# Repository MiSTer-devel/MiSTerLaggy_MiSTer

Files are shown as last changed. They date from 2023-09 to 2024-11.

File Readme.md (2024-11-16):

# MiSTer Laggy

MiSTer Laggy is a display latency tester for use with the MiSTer FPGA system. It consists of a core that runs on the MiSTer DE-10 and a light sensor that connects to the MiSTer's User Port. It operates on the same principle as the [Time Sleuth](https://github.com/chriz2600/time-sleuth) but takes advantage of an existing platform to generate the video signal and capture the measurements.

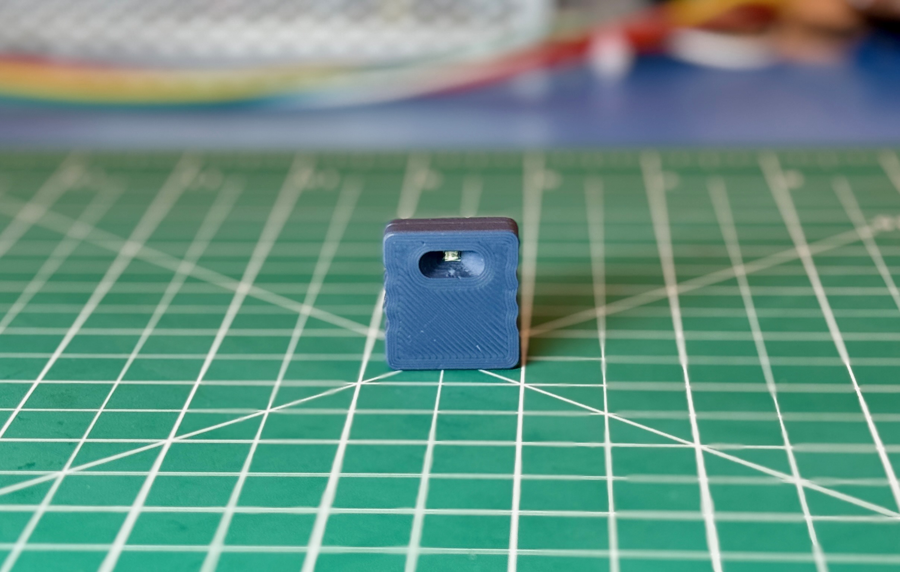
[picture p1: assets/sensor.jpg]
Sensor


## Setup
* Copy the latest core from the `releases/` directory to your MiSTer
* Connect the MiSTer Laggy sensor to the User Port with a USB A-C cable
* Launch the MiSTer Laggy core

## Basic Operation
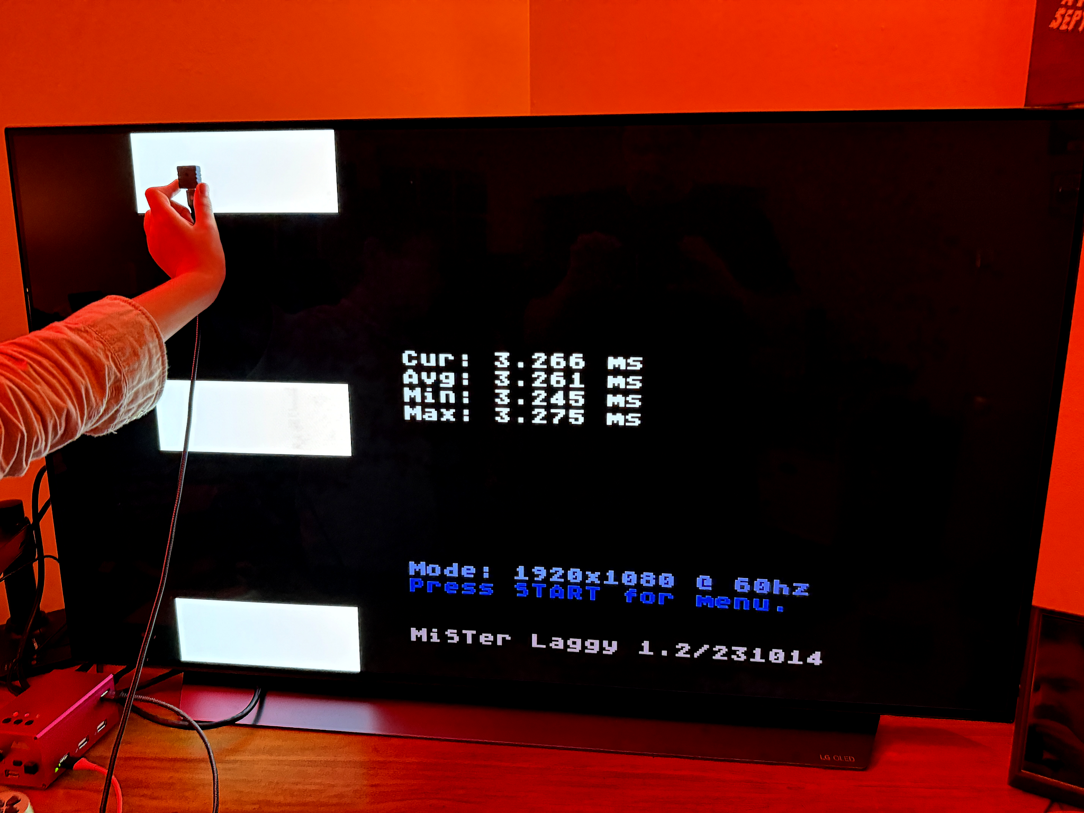
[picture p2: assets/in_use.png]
In Use

The system works by flashing a test pattern on the screen and measuring how long it takes for that pattern to be seen by the sensor. The measured latency is show in the center of the screen, along with the average, min and max measures. There are three areas in the test pattern why you can place the sensor, so you can measure latency at the top, middle and bottom of the screen.

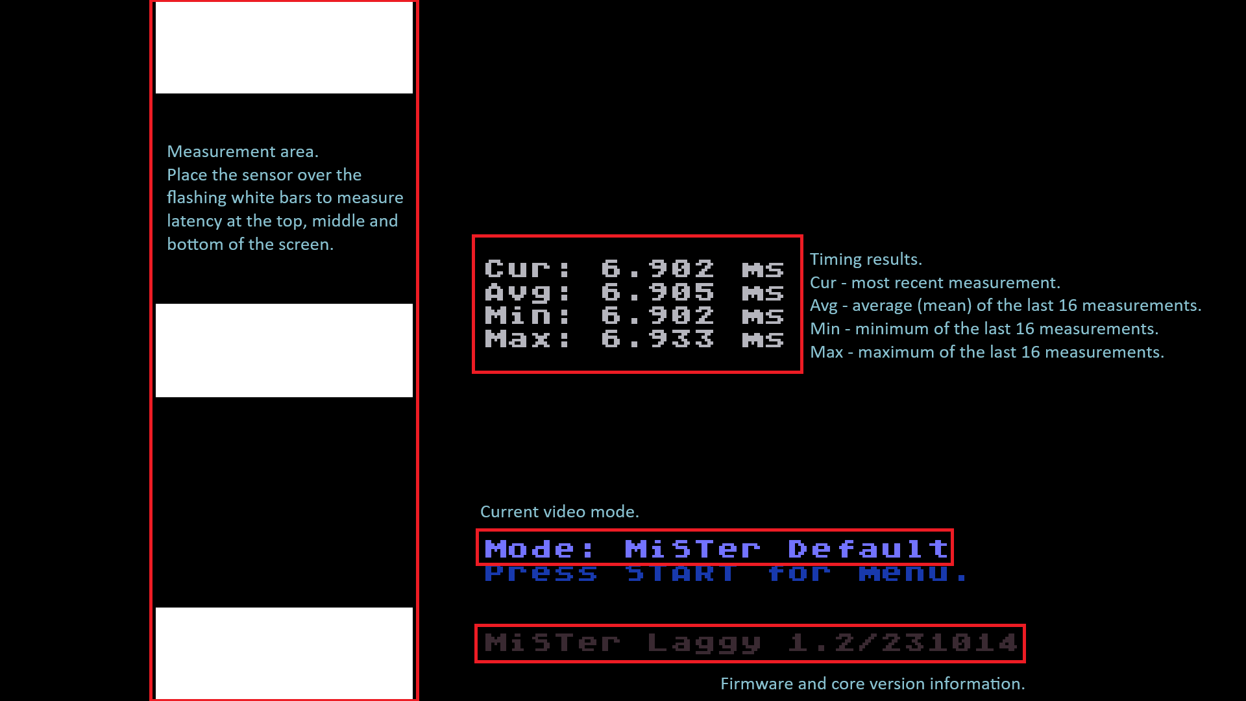
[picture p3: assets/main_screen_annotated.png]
Annotated Main Screen


## Video Modes
On startup or after a reset, the core uses whatever video mode and `vsync_adjust` settings you have configured in your MiSTer INI file. When running in this mode it will display `Mode: MiSTer Default` on the main screen. You can change the current video mode in the _Video Config_ menu which you access by pressing the START button on your controller.

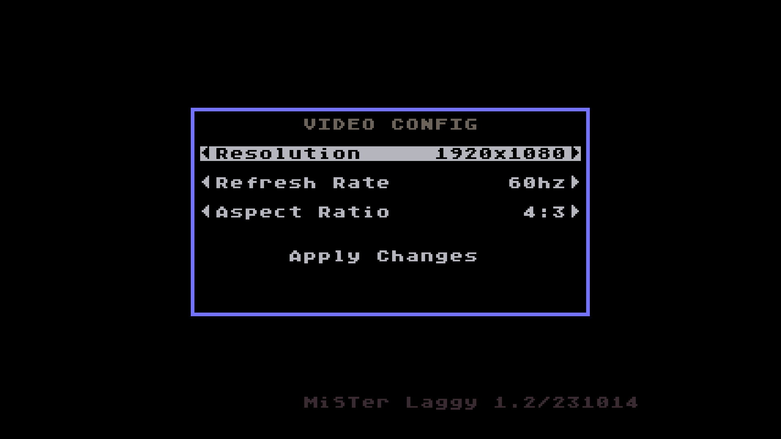
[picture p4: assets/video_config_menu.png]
Video Config Menu


In the Video Config menu you can select between several resolutions and refresh rates. Up/Down on your controller selects between the options while Left/Right adjusts each value. You can press B or Start to back out of the menu at any time. To apply the changes and switch to the mode you have selected, highlight the _Apply Changes_ option and press A. The core will switch to the new video mode and return to the main screen. The new mode will now be displayed in the `Mode:` area.

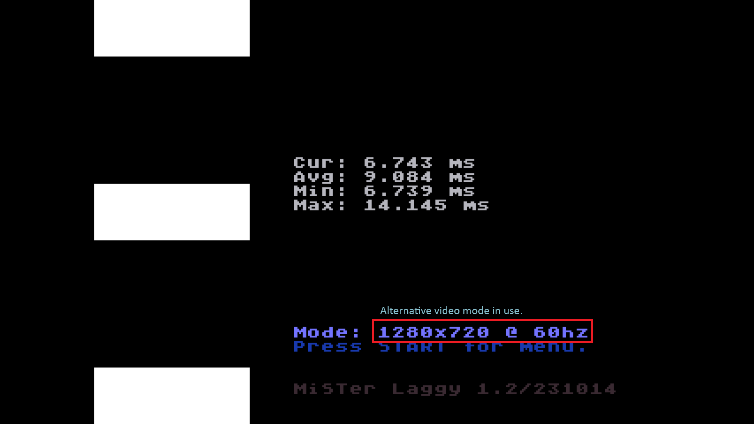
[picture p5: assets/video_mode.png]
Alternative Mode


It's possible that your display does not support the display mode that you have selected. If that happens you can just reset the core by pressing the `User` button on your IO board or just power cycle your MiSTer. None of the changes set in the Video Config menu are permanent.

## Timing Details
MiSTer Laggy starts counting latency from the moment the vertical blank ends. Assuming there is no overscan or other scaling enabled on your display, this will be the where the first visible line in drawn on your screen. With HDMI output on MiSTer there are two different vertical blanks, the vertical blank created by the core itself and the vertical blank created by the scaler. The scaler vertical blank occurs after the cores vertical blank, how long after depends on the `vsync_adjust` setting you are using in your INI.

When the MiSTer Laggy core starts up and is in the `MiSTer Default` video mode, it uses the end of the vertical blank from the core as the start of the measurement. This means that any latency introduced by MiSTer's ASCAL scaler will also be measured. You could, for instance, experiment with different `vsync_adjust` settings and see how they impact the total latency.

When you switch modes in the Video Config menu, the core will start using the end of the HDMI vertical blank, which is generated by the scaler, as the start of the measurement period. This means only the display latency will be measured, and any additional time spent in the MiSTers scaler will not be included. 

## Hardware
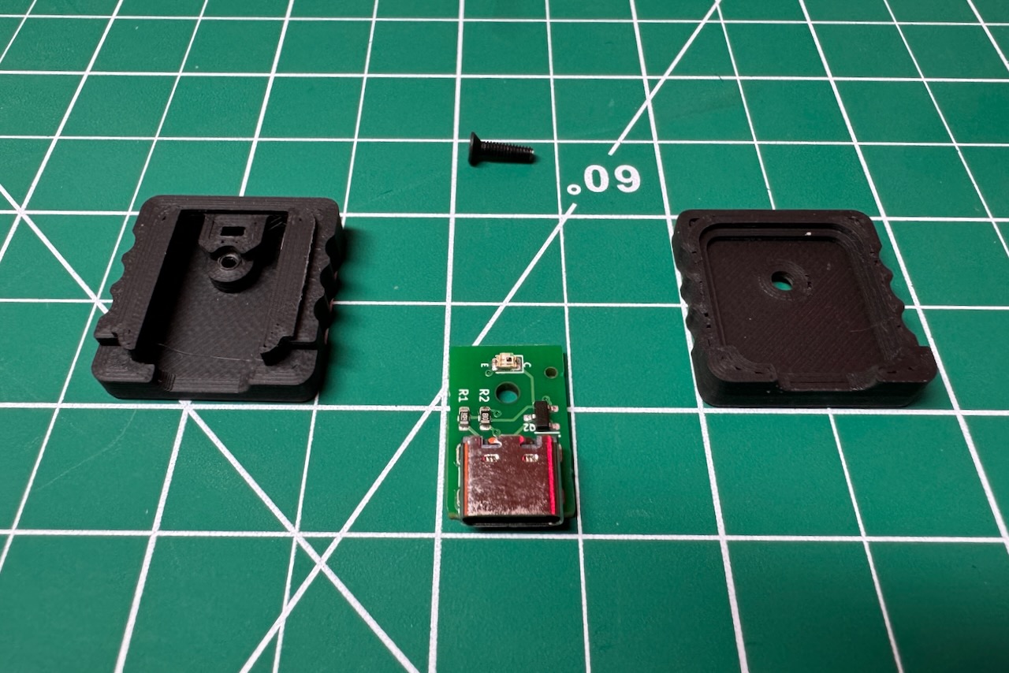
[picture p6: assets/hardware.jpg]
Hardware

The MiSTer Laggy hardware is very simple. It consists of a small PCB with a photo transistor alongside a few components to allow it to interface with the user port, and a 3D printed case. The case is designed to prevent any external light from reaching the sensor. It snaps together tightly and is secured with a M2x8 flat head screw. The PCB is all surface mounted components and uses a compact USB-C connector.

The `hardware/` directory contains KiCAD project files for the PCB along with STEP and STL files for the case.

## Additional Assets
32x32 MiSTer Kun logo - https://github.com/baxysquare/mister_kun

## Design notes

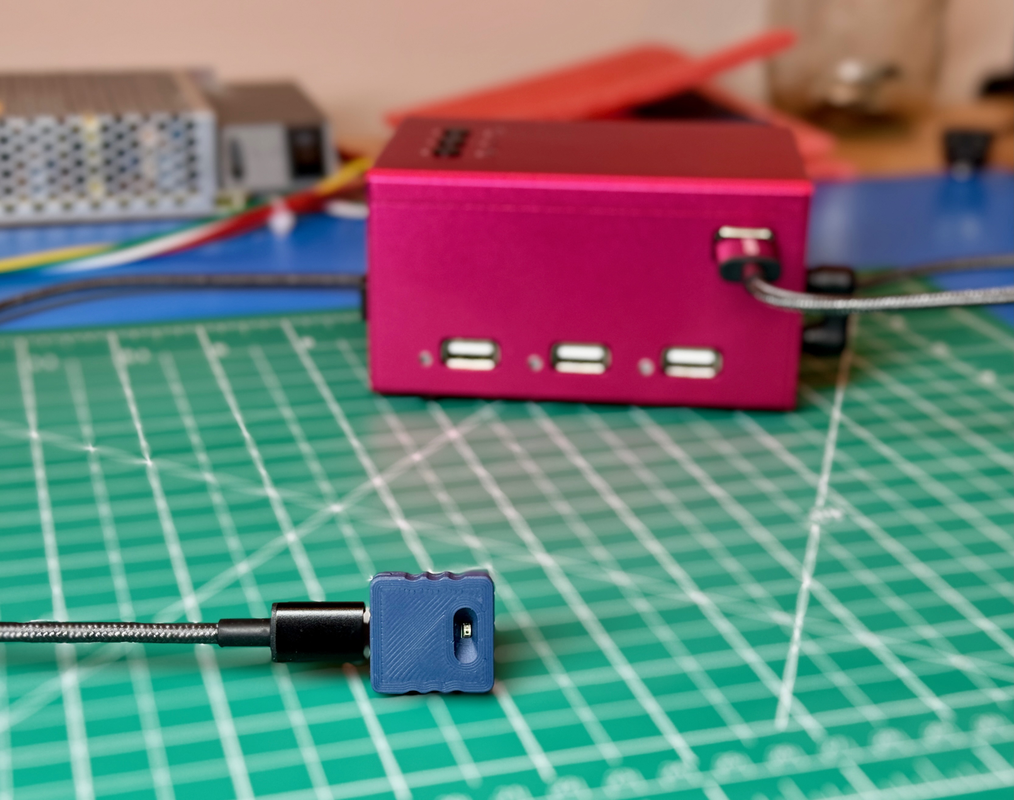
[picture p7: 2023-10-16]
assets/sensor_with_mister.jpg

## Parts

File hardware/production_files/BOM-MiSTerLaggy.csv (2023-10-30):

Comment | Designator | Footprint | LCSC
PT17-21C/L41/TR8 | Q1 | LED_0805_2012Metric | C100090
1K | R2 | R_0603_1608Metric | C21190
300K | R1 | R_0603_1608Metric | C23024
USB_C_Receptacle_USB2.0 | J1 | USB_C_Receptacle_G-Switch_GT-USB-7010ASV | C2988369
2N7002 | Q2 | SOT-23 | C8545

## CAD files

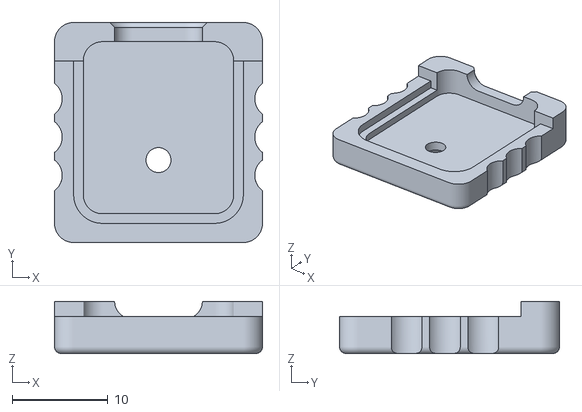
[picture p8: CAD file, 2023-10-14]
hardware/Case - Back Side.stl
21.7 x 23.0 x 5.43

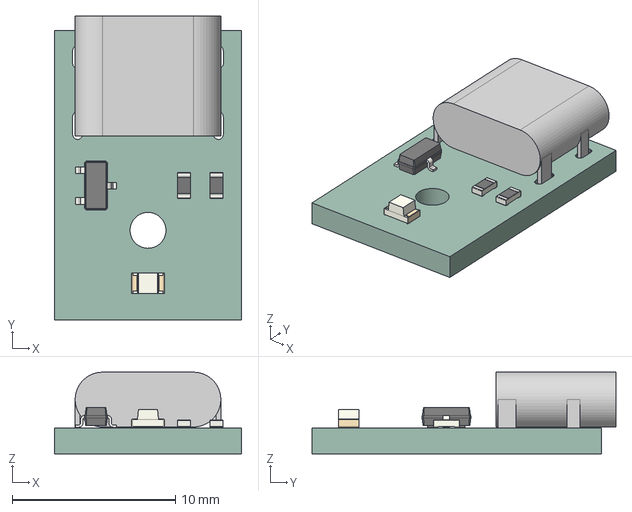
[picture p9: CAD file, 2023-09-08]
hardware/SMD/MiSTerLaggy.step
11.5 x 18.6 x 5.01 mm
MiSTerLaggy PCB

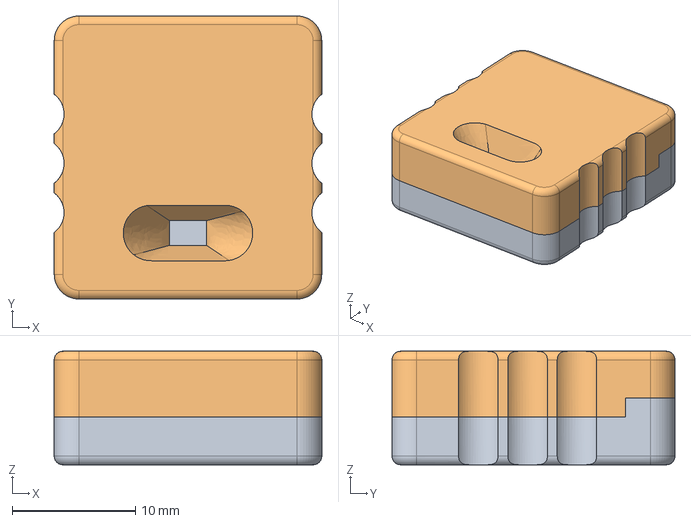
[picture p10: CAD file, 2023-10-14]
hardware/Case.step
21.7 x 22.9 x 9.21 mm

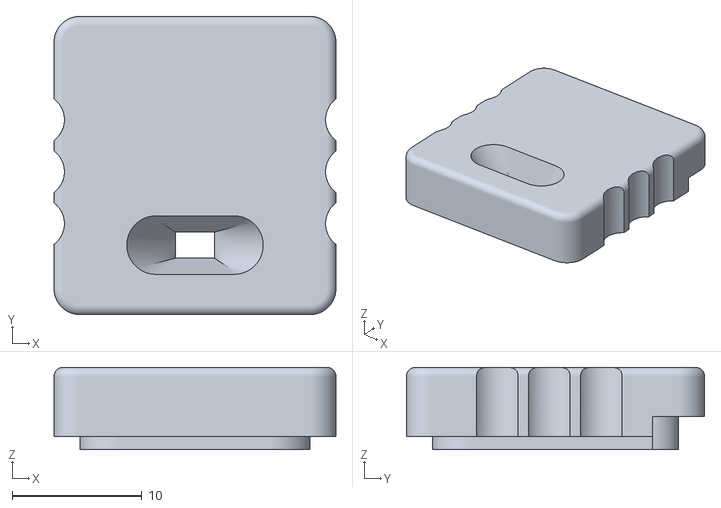
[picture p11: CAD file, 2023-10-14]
hardware/Case - Sensor Side.stl
21.7 x 23.0 x 6.33

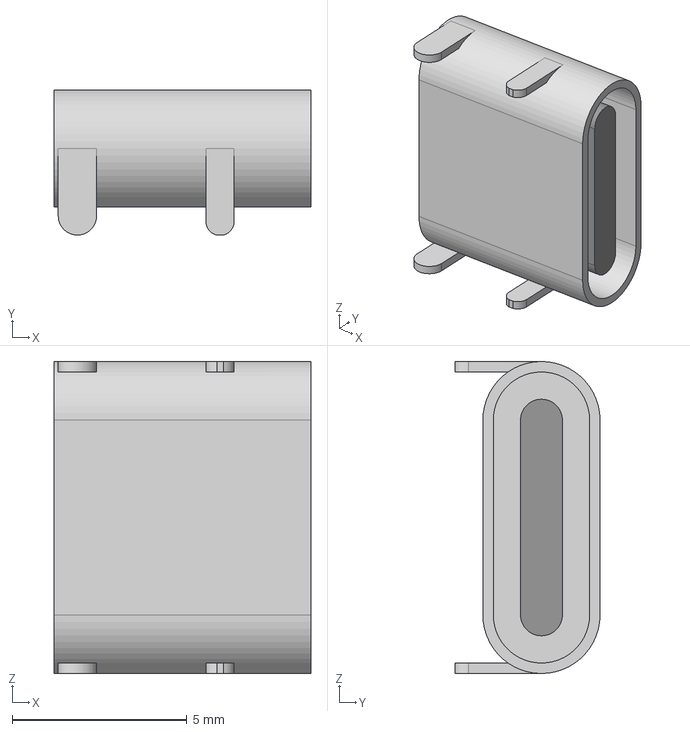
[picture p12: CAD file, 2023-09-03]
hardware/GT-USB-7010ASV.step
7.35 x 4.16 x 8.94 mm

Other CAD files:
hardware/MiSTerLaggy-PCB.step

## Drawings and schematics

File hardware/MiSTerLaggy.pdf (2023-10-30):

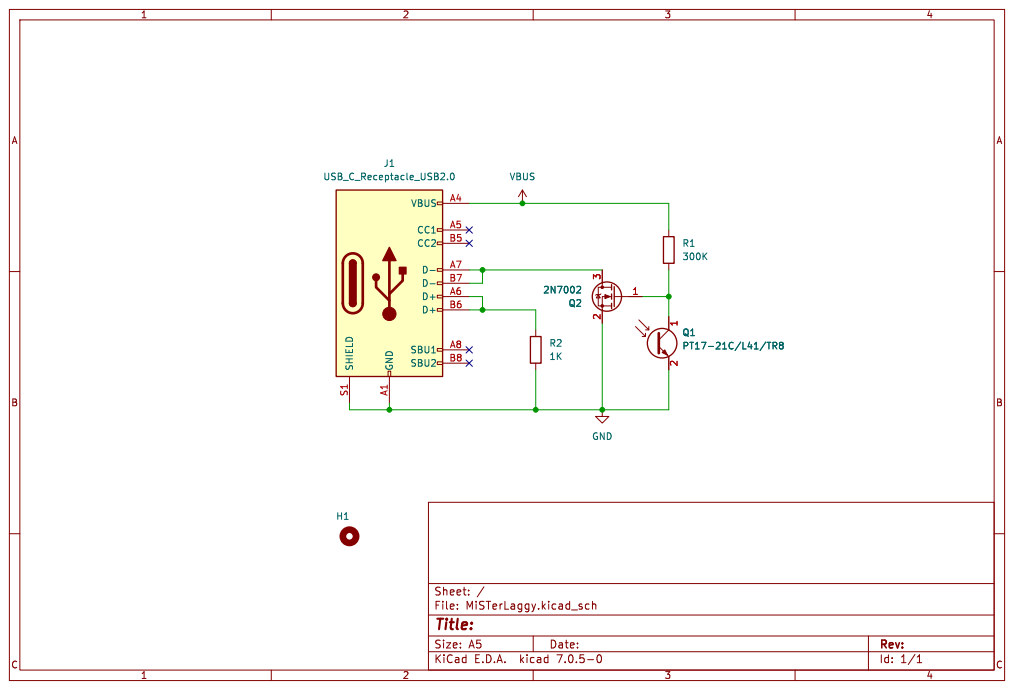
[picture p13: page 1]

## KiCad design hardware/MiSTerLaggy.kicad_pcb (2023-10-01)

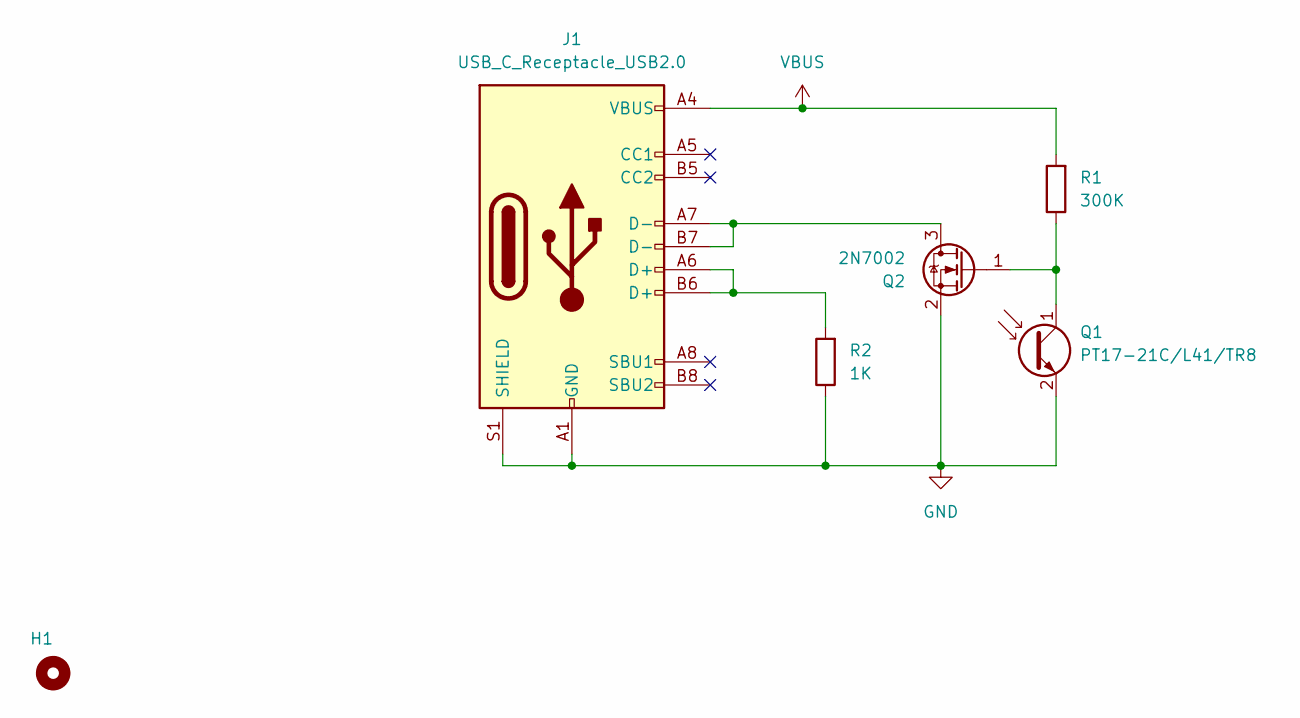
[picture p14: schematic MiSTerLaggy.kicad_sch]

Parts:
H1: MountingHole; MountingHole_2.2mm_M2_ISO7380
J1: USB_C_Receptacle_USB2.0; USB_C_Receptacle_G-Switch_GT-USB-7010ASV
Q1: PT17-21C/L41/TR8; LED_0805_2012Metric
Q2: 2N7002; SOT-23
R1: 300K; R_0603_1608Metric
R2: 1K; R_0603_1608Metric

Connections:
GND: J1.A1 (GND), J1.A12 (GND), J1.B1 (GND), J1.B12 (GND), J1.S1 (SHIELD), Q1.2 (E), Q2.2 (S), R2.1
unnamed: J1.A6 (D+), J1.B6 (D+), R2.2
unnamed: Q1.1 (C), Q2.1 (G), R1.1
unnamed: J1.A7 (D-), J1.B7 (D-), Q2.3 (D)
VBUS: J1.A4 (VBUS), J1.A9 (VBUS), J1.B4 (VBUS), J1.B9 (VBUS), R1.2

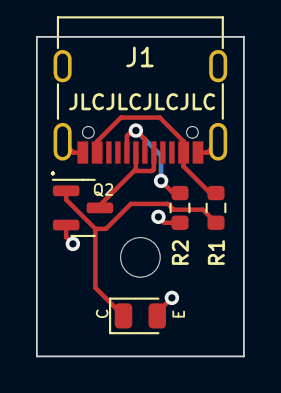
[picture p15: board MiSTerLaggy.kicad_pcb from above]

Board: 2 copper layers, 11.5 x 17.8 mm, 6 parts (0 on the bottom side), 5 nets.

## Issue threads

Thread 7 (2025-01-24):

Won't get past "No sensor detected!"

AndreTheShepherd, 2025-01-24:
Hi,

using MiSTer Laggy 1.3/241113
Sensor connected to User Port at the IO Board
I tried different cables, but I cannot get past the "No sensor detected" message.

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

Mister ini attached. [MiSTer_test_ini.txt](https://github.com/user-attachments/files/18539704/MiSTer_test_ini.txt)

I'd love to rule out a hardware issue with the sensor itself. Do you have a hint how to test the sensor hardware for functionality?

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

Any other ideas what I can try?

Thanks a lot for the great work and support.

Kindest regards

wickerwaka, 2025-01-24:
The detection is really basic. That R2 resistor pulls down one of the signals and that is what the software looks for. If there is no obvious physical damage to the port or the PCB then I would suspect something else.

Have you tried with a different cable?
Have you ever had anything else connected and working in the User IO port?
Does you IO board have the required pins for the user IO port to work? Sometimes they are no installed by manufacturers.

AndreTheShepherd, 2025-01-26:
The hardware of the sensor looks fine, port and all the surface mounted components

Tried different cables: CHECK, 3 different cable. That should be fine
Anything else on the User Port: NOPE ...

wickerwaka, 2025-02-01:
Perfect! Thank you for posting the solution.

Closed 2025-02-01.

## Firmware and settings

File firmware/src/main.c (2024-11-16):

#include <stdint.h>
#include <stdbool.h>
#include "printf/printf.h"

#include "util.h"
#include "interrupts.h"
#include "input.h"
#include "hdmi.h"
#include "gfx.h"
#include "clock.h"
#include "debug.h"

#define FIRMWARE_VERSION "1.3"

#define RGB(r, g, b) ( ( ((r) & 0xf8) << 7 ) | ( ((g) & 0xf8) << 2 ) | ( ((b) & 0xf8) >> 3 ) )

#define WAIT_CLEAR_TICKS CLOCK_MS_TO_TICKS(200)
#define MIN_SAMPLE_TICKS CLOCK_MS_TO_TICKS(200)
#define MAX_SAMPLE_TICKS CLOCK_MS_TO_TICKS(500)

uint16_t *palette_ram = (uint16_t *)0x920000;
volatile uint16_t *user_io = (volatile uint16_t *)0x300000;
uint16_t *int_ctrl = (uint16_t *)0x700000;
uint32_t *core_version = (uint32_t *)0xf00000;

#define INT2_CTRL(x) (((x) & 0xf) << 0)
#define INT4_CTRL(x) (((x) & 0xf) << 4)
#define INT6_CTRL(x) (((x) & 0xf) << 8)
#define INT_SRC_NONE 0
#define INT_SRC_VBLANK 1
#define INT_SRC_HDMI_VBLANK 2
#define INT_SRC_USERIO 3
#define INT_INVERT 0x8


volatile uint32_t vblank_int_count = 0;

volatile uint16_t sample_seq = 0; 
volatile uint16_t frame_seq = 0;
volatile uint16_t sensor_seq = 0;

volatile uint32_t frame_ticks = 0;
volatile uint32_t sensor_ticks = 0;


__attribute__((interrupt)) void level2_handler()
{
    DEBUG_FRAME_MARKER(vblank_start);
    vblank_int_count++;
}

__attribute__((interrupt)) void level4_handler()
{
    if (frame_seq != sample_seq)
    {
        frame_ticks = clock_get_ticks();
        frame_seq = sample_seq;
    }

    DEBUG_FRAME_MARKER(vblank_end);
}

__attribute__((interrupt)) void level6_handler()
{
    if (sensor_seq != sample_seq)
    {
        sensor_ticks = clock_get_ticks();
        sensor_seq = sample_seq;
    }
}


static uint32_t rand_state = 0xdeadbeef;
uint32_t rand32()
{
 	uint32_t x = rand_state;
	x ^= x << 13;
	x ^= x >> 17;
	x ^= x << 5;
    rand_state = x;
	return x;
}


#define STATUS_W 16
#define STATUS_H 4
typedef struct
{
    char lines[STATUS_H][STATUS_W+1];
    uint8_t colors[STATUS_H];
} StatusInfo;

StatusInfo status;

int test_position = 0;
static inline Align align_test()
{
    return test_position == 0 ? ALIGN_LEFT : ALIGN_RIGHT;
}

static inline Align align_info()
{
    return test_position == 0 ? ALIGN_RIGHT : ALIGN_LEFT;
}

char video_mode_desc[32];

static void draw_status()
{
    gfx_begin_window(ALIGN_MIDDLE | align_info(), 2, -2, 24, STATUS_H, 0);

    for( int i = 0; i < STATUS_H; i++ )
    {
        gfx_pen(status.colors[i]);
        gfx_text(status.lines[i]);
    }

    gfx_end_window();
}

typedef struct
{
    uint16_t width;
    uint16_t height;
    bool wide;
} HDMIResolution;

static const HDMIResolution hdmi_resolutions[] =
{
    {  640,  480, false },
    {  800,  600, false },
    { 1280,  720, true },
    { 1024,  768, false },
    { 1366,  768, false },
    { 1280,  960, false },
    { 1708,  960, true },
    { 1920, 1080, true },
    { 1600, 1200, false },
    { 1792, 1344, false },
    { 1920, 1440, false },
    { 2048, 1536, false }
};

static const int hdmi_refresh_rates[] =
{
    24,
    30,
    50,
    51,
    52,
    53,
    54,
    55,
    56,
    57,
    58,
    59,
    60,
    61,
    62,
    63,
    64,
    65,
    72
};

static const char *resolution_to_string(const void *options, int index)
{
    static char tmp[32];

    const HDMIResolution *res = (const HDMIResolution *)options;

    snprintf(tmp, sizeof(tmp), "%ux%u", res[index].width, res[index].height);

    return tmp;
}

static const char *refresh_to_string(const void *options, int index)
{
    static char tmp[10];

    const int *hz = (const int *)options;

    snprintf(tmp, sizeof(tmp), "%dhz", hz[index]);

    return tmp;
}

static bool draw_menu(bool reset)
{
    static int mode_idx = 0;
    static int refresh_idx = 0;
    static int aspect_idx = 0;
    static int applied_mode_idx = -1;
    static int applied_refresh_idx = -1;
    static int applied_aspect_idx = -1;

    static MenuContext menuctx = INIT_MENU_CONTEXT;

    bool close_menu = false;

    if (reset)
    {
        if (applied_mode_idx >= 0)
        {
            mode_idx = applied_mode_idx;
            refresh_idx = applied_refresh_idx;
            aspect_idx = applied_aspect_idx;
        }
        else
        {
            mode_idx = 7;
            refresh_idx = 12;
            aspect_idx = 0;
        }
    }

    gfx_clear();

    gfx_begin_menu("CONFIG", 28, 18, &menuctx);
    
    gfx_menuitem_select_func("Resolution", hdmi_resolutions, ARRAY_COUNT(hdmi_resolutions), resolution_to_string, &mode_idx);
    gfx_menuitem_select_func("Refresh Rate", hdmi_refresh_rates, ARRAY_COUNT(hdmi_refresh_rates), refresh_to_string, &refresh_idx);

    if (hdmi_resolutions[mode_idx].wide)
    {
        const char *aspects[2] = { "4:3", "16:9" };
        gfx_menuitem_select("Aspect Ratio", aspects, 2, &aspect_idx);
    }
    else
    {
        gfx_newline(2);
    }

    gfx_newline(1);

    if (mode_idx != applied_mode_idx || refresh_idx != applied_refresh_idx || aspect_idx != applied_aspect_idx)
    {
        if (gfx_menuitem_button("Apply Video Changes"))
        {
            bool wide = hdmi_resolutions[mode_idx].wide && (aspect_idx == 1);
            *int_ctrl = INT2_CTRL(INT_SRC_VBLANK) | INT4_CTRL(INT_SRC_HDMI_VBLANK | INT_INVERT) | INT6_CTRL(INT_SRC_USERIO);
            gfx_set_240p(hdmi_refresh_rates[refresh_idx], wide);
            hdmi_set_mode(hdmi_resolutions[mode_idx].width, hdmi_resolutions[mode_idx].height, hdmi_refresh_rates[refresh_idx]);
            applied_mode_idx = mode_idx;
            applied_refresh_idx = refresh_idx;
            applied_aspect_idx = aspect_idx;
            close_menu = true;

            snprintf(video_mode_desc, sizeof(video_mode_desc), "%s @ %s",
                        resolution_to_string(hdmi_resolutions, mode_idx),
                        refresh_to_string(hdmi_refresh_rates, refresh_idx));
        }
    }

    gfx_newline(2);
    const char *test_positions[2] = { "Left", "Right" };
    gfx_menuitem_select("Test Position", test_positions, 2, &test_position);

    gfx_end_menu();

    if (input_pressed() & (INPUT_MENU | INPUT_BACK))
    {
        close_menu = true;
    }

    return !close_menu;
}

uint32_t vblank_count = 0;
void wait_vblank()
{
    while (vblank_count == vblank_int_count) {};

    vblank_count = vblank_int_count;
}

typedef enum
{
    ST_CLEAR = 0,
    ST_WAIT_CLEAR,
    ST_START_SAMPLE,
    ST_WAIT_SAMPLE,
    ST_END_SAMPLE,
} State;

State state = ST_CLEAR;
uint32_t state_start_ticks;

static void set_state(State s)
{
    state = s;
    state_start_ticks = clock_get_ticks();
}

int ticks_to_ms_str(uint32_t ticks, char *str, int len)
{
    uint32_t ms, us;
    clock_ticks_to_ms_us(ticks, &ms, &us);
    return snprintf(str, len, "%u.%03u", ms, us);
}

#define HISTORY_SIZE 16
uint32_t samples[HISTORY_SIZE];
uint32_t latest_sample;
uint32_t sample_idx = 0;
typedef enum
{
    NO_SAMPLE,
    NEW_SAMPLE,
    MISSING_SAMPLE
} SampleStatus;

SampleStatus sample_status;

void record_new_sample(uint32_t ticks)
{
    latest_sample = ticks;
    samples[sample_idx % HISTORY_SIZE] = ticks;
    sample_idx++;
    sample_status = NEW_SAMPLE;
}

void record_missing_sample()
{
    sample_status = MISSING_SAMPLE;
}

void update_sample_status()
{
    uint32_t min_ticks = 0xffffffff;
    uint32_t max_ticks = 0x00000000;
    uint32_t total_ticks = 0;

    int history_len = HISTORY_SIZE > sample_idx ? sample_idx : HISTORY_SIZE;

    for( int i = 0; i < history_len; i++ )
    {
        uint32_t ticks = samples[i];
        total_ticks += ticks;

        if (ticks > max_ticks) max_ticks = ticks;
        if (ticks < min_ticks) min_ticks = ticks;
    }

    uint32_t mean_ticks = total_ticks / history_len;

    status.colors[0] = TEXT_GRAY;
    status.colors[1] = TEXT_GRAY;
    status.colors[2] = TEXT_GRAY;
    status.colors[3] = TEXT_GRAY;

    char ms_str1[16], ms_str2[16];
    ticks_to_ms_str(latest_sample, ms_str1, 16);
    ticks_to_ms_str(mean_ticks, ms_str2, 16);
    snprintf(status.lines[0], STATUS_W, "Cur: %s ms", ms_str1);
    snprintf(status.lines[1], STATUS_W, "Avg: %s ms", ms_str2);

    ticks_to_ms_str(min_ticks, ms_str1, 16);
    ticks_to_ms_str(max_ticks, ms_str2, 16);
    snprintf(status.lines[2], STATUS_W, "Min: %s ms", ms_str1);
    snprintf(status.lines[3], STATUS_W, "Max: %s ms", ms_str2);
}

typedef enum { MODE_NO_SENSOR, MODE_SAMPLING, MODE_MENU } MainMode;

#define BAR_W 11
#define BAR_H 4

void do_sampling()
{
    uint32_t cur_ticks = clock_get_ticks();
    uint32_t state_ticks = cur_ticks - state_start_ticks;

    switch (state)
    {
        case ST_CLEAR:
            palette_ram[0x80] = 0x0000;
            set_state(ST_WAIT_CLEAR);
            break;

        case ST_WAIT_CLEAR:
            if (state_ticks >= WAIT_CLEAR_TICKS)
            {
                set_state(ST_START_SAMPLE);
            }
            break;

        case ST_START_SAMPLE:
            set_state(ST_WAIT_SAMPLE);
            palette_ram[0x80] = 0xffff;
            sample_seq++;
            DEBUG_FRAME_MARKER(sample_start);
            break;

        case ST_WAIT_SAMPLE:
            if (state_ticks < MIN_SAMPLE_TICKS)
            {
                break;
            }

            if (state_ticks > MAX_SAMPLE_TICKS)
            {
                set_state(ST_CLEAR);
                record_missing_sample();
            }
            else if (sample_seq == frame_seq && sample_seq == sensor_seq)
            {
                set_state(ST_CLEAR);
                if (frame_ticks >= sensor_ticks)
                {
                    record_missing_sample();
                }
                else
                {
                    uint32_t tick_diff = sensor_ticks - frame_ticks;
                    record_new_sample(tick_diff);
                }
            }
            break;

        default:
            set_state(ST_CLEAR);
            break;
    }


    gfx_clear();
    gfx_pen(TEXT_DARK_GRAY);
    gfx_display_border();

    gfx_pen(0x80);

    int16_t rx, ry;
    gfx_align_box(align_test() | ALIGN_TOP, 0, 0, BAR_W, BAR_H, &rx, &ry);
    gfx_rect(rx, ry, BAR_W, BAR_H);

    gfx_align_box(align_test() | ALIGN_MIDDLE, 0, 0, BAR_W, BAR_H, &rx, &ry);
    gfx_rect(rx, ry, BAR_W, BAR_H);

    gfx_align_box(align_test() | ALIGN_BOTTOM, 0, 0, BAR_W, BAR_H, &rx, &ry);
    gfx_rect(rx, ry, BAR_W, BAR_H);

    gfx_align_box(align_info() | ALIGN_TOP, 2, 2, 4, 4, &rx, &ry);
    if ((rand32() & 0xff33) == 0x0000)
        gfx_image(0x80 + 16, 0x40, rx, ry, 4, 4);
    else
        gfx_image(0x80, 0x40, rx, ry, 4, 4);

    gfx_begin_window(ALIGN_BOTTOM | align_info(), 2, 5, 24, 2, 0);
    gfx_pen(TEXT_BLUE);
    gfx_textf("Mode: %s", video_mode_desc);
    gfx_pen(TEXT_DARK_BLUE);
    gfx_text("Press START for menu.");
    gfx_end_window();

    draw_status();

    switch (sample_status)
    {
        case MISSING_SAMPLE:
            status.colors[0] = TEXT_ORANGE;
            snprintf(status.lines[0], STATUS_W, "CUR: NO SAMPLE");
            break;

        case NEW_SAMPLE:
            update_sample_status();
            break;

        case NO_SAMPLE:
        default:
            break;
    }

    sample_status = NO_SAMPLE;
}

void draw_no_sensor()
{
    gfx_clear();
    gfx_pen(TEXT_RED);
    gfx_begin_window(ALIGN_CENTER | ALIGN_MIDDLE, 0, 0, 34, 6, 1);

    gfx_text_aligned(ALIGN_CENTER, "No sensor detected!");
    gfx_newline(1);
    gfx_pen(TEXT_ORANGE);
    gfx_text_aligned(ALIGN_LEFT, "Connect your MiSTer Laggy sensor");
    gfx_text_aligned(ALIGN_LEFT, "to the User Port.");
    
    gfx_end_window();
}

void draw_version()
{
    gfx_pen(TEXT_DARK);
    gfx_begin_window(ALIGN_BOTTOM | align_info(), 2, 2, 24, 1, 0);
    gfx_textf_aligned(ALIGN_LEFT, "MiSTer Laggy %s/%06u", FIRMWARE_VERSION, *core_version);
    gfx_end_window();
}

uint16_t base_palette[16] =
{
    RGB(0x3f, 0x28, 0x32),
    RGB(0x68, 0x60, 0x5c),
    RGB(0xb0, 0xb0, 0xb8),
    RGB(0xfc, 0xfc, 0xfc),
    RGB(0x1c, 0x38, 0xac),
    RGB(0x70, 0x70, 0xfc),
    RGB(0xa8, 0x28, 0x14),
    RGB(0xfc, 0x48, 0x48),
    RGB(0x20, 0x88, 0x00),
    RGB(0x70, 0xf8, 0x28),
    RGB(0xb8, 0x2c, 0xd0),
    RGB(0xfc, 0x74, 0xec),
    RGB(0xac, 0x58, 0x1c),
    RGB(0xf8, 0xa8, 0x50),
    RGB(0x3c, 0xd4, 0xe4),
    RGB(0xf8, 0xec, 0x20)
};

void set_palette()
{
    for( int i = 0; i < 16; i++ )
    {
        palette_ram[(i << 1) + 0] = RGB(0, 0, 0);
        palette_ram[(i << 1) + 1] = base_palette[i];
    }

    palette_ram[0x20] = RGB(0,0,0);
    palette_ram[0x21] = RGB(0xff,0xff,0xff);

    /* Misterkun */
    palette_ram[0x40] = RGB(0,0,0);
    palette_ram[0x41] = RGB(8,8,8);
    palette_ram[0x42] = RGB(187,187,187);
    palette_ram[0x43] = RGB(232,126,182);
    palette_ram[0x44] = RGB(240,148,191);
    palette_ram[0x45] = RGB(247,246,246);
    palette_ram[0x46] = RGB(255,255,255);
    palette_ram[0x47] = RGB(52,52,72);

    palette_ram[0x80] = RGB(0,0,0);
}

int main(int argc, char *argv[])
{
    char tmp[64];

    MainMode mode = MODE_SAMPLING;
    strcpy(video_mode_desc, "MiSTer Default");

    set_palette();

    *user_io = 0xffff;
    *int_ctrl = INT2_CTRL(INT_SRC_VBLANK) | INT4_CTRL(INT_SRC_VBLANK | INT_INVERT) | INT6_CTRL(INT_SRC_USERIO);

    memset(&status, 0, sizeof(status));

    gfx_set_240p(60, false);

    enable_interrupts();

    bool new_mode = true;

    while (true)
    {
        wait_vblank();
        gfx_pageflip();
        input_poll();

        if (mode == MODE_SAMPLING)
        {
            new_mode = false;
            do_sampling();
            if (input_pressed() & INPUT_MENU)
            {
                mode = MODE_MENU;
                new_mode = true;
            }

            if (*user_io & 0x0001)
            {
                mode = MODE_NO_SENSOR;
                new_mode = true;
            }
        }
        else if (mode == MODE_MENU)
        {
            if( !draw_menu(new_mode) )
            {
                mode = MODE_SAMPLING;
                new_mode = true;
            }
            else
            {
                new_mode = false;
            }
        }
        else if (mode == MODE_NO_SENSOR)
        {
            if (!(*user_io & 0x0001))
            {
                mode = MODE_SAMPLING;
                new_mode = true;
            }
            draw_no_sensor();
        }

        draw_version();

        DEBUG_DRAW();

        DEBUG_FRAME_MARKER(frontend_end);
        DEBUG_END_FRAME();
    }

    return 0;
}

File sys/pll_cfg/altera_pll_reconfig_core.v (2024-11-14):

// (C) 2001-2017 Intel Corporation. All rights reserved.
// Your use of Intel Corporation's design tools, logic functions and other 
// software and tools, and its AMPP partner logic functions, and any output 
// files any of the foregoing (including device programming or simulation 
// files), and any associated documentation or information are expressly subject 
// to the terms and conditions of the Intel Program License Subscription 
// Agreement, Intel MegaCore Function License Agreement, or other applicable 
// license agreement, including, without limitation, that your use is for the 
// sole purpose of programming logic devices manufactured by Intel and sold by 
// Intel or its authorized distributors.  Please refer to the applicable 
// agreement for further details.


`timescale 1ps/1ps

module altera_pll_reconfig_core
#(
    parameter 	reconf_width       	= 64,
    parameter 	device_family       	= "Cyclone V",
    // MIF Streaming parameters
    parameter   RECONFIG_ADDR_WIDTH     = 6,
    parameter   RECONFIG_DATA_WIDTH     = 32,
    parameter   ROM_ADDR_WIDTH          = 9,
    parameter   ROM_DATA_WIDTH          = 32,
    parameter	ROM_NUM_WORDS           = 512
) ( 

    //input
    input   wire    mgmt_clk,
    input   wire    mgmt_reset,


    //conduits
    output  wire [reconf_width-1:0] reconfig_to_pll,
    input  wire [reconf_width-1:0] reconfig_from_pll,

    // user data (avalon-MM slave interface)
    output  wire [31:0] mgmt_readdata,
    output  wire        mgmt_waitrequest,
    input   wire [5:0]  mgmt_address,
    input   wire        mgmt_read,
    input   wire        mgmt_write,
    input   wire [31:0] mgmt_writedata,

    //other
    output  wire        mif_start_out,
    output  reg [ROM_ADDR_WIDTH-1:0]    mif_base_addr
);
    localparam mode_WR            = 1'b0;
    localparam mode_POLL          = 1'b1;
    localparam MODE_REG           = 6'b000000;
    localparam STATUS_REG         = 6'b000001;
    localparam START_REG          = 6'b000010;
    localparam N_REG              = 6'b000011;
    localparam M_REG              = 6'b000100;
    localparam C_COUNTERS_REG     = 6'b000101;
    localparam DPS_REG            = 6'b000110;
    localparam DSM_REG            = 6'b000111;
    localparam BWCTRL_REG         = 6'b001000;
    localparam CP_CURRENT_REG     = 6'b001001;
    localparam ANY_DPRIO          = 6'b100000;
    localparam CNT_BASE           = 5'b001010;
    localparam VCO_REG              = 6'b011100;
    localparam MIF_REG            = 6'b011111;
    
    //C Counters
    localparam number_of_counters = 5'd18;
    localparam  CNT_0 = 1'd0, CNT_1 = 5'd1, CNT_2 = 5'd2,
                CNT_3 = 5'd3, CNT_4 = 5'd4, CNT_5 = 5'd5,
                CNT_6 = 5'd6, CNT_7 = 5'd7, CNT_8 = 5'd8,
                CNT_9 = 5'd9, CNT_10 = 5'd10, CNT_11 = 5'd11,
                CNT_12 = 5'd12, CNT_13 = 5'd13, CNT_14 = 5'd14,
                CNT_15 = 5'd15, CNT_16 = 5'd16, CNT_17 = 5'd17;
    //C counter addresses
    localparam C_CNT_0_DIV_ADDR = 5'h00;
    localparam C_CNT_0_DIV_ADDR_DPRIO_1 = 5'h11;
    localparam C_CNT_0_3_BYPASS_EN_ADDR = 5'h15;
    localparam C_CNT_0_3_ODD_DIV_EN_ADDR = 5'h17;
    localparam C_CNT_4_17_BYPASS_EN_ADDR = 5'h14;
    localparam C_CNT_4_17_ODD_DIV_EN_ADDR = 5'h16;
    //N counter addresses
    localparam N_CNT_DIV_ADDR = 5'h13;
    localparam N_CNT_BYPASS_EN_ADDR = 5'h15;
    localparam N_CNT_ODD_DIV_EN_ADDR = 5'h17;
    //M counter addresses
    localparam M_CNT_DIV_ADDR = 5'h12;
    localparam M_CNT_BYPASS_EN_ADDR = 5'h15;
    localparam M_CNT_ODD_DIV_EN_ADDR = 5'h17;
    
    //DSM address
    localparam DSM_K_FRACTIONAL_DIVISION_ADDR_0 = 5'h18;
    localparam DSM_K_FRACTIONAL_DIVISION_ADDR_1 = 5'h19;
    localparam DSM_K_READY_ADDR = 5'h17;
    localparam DSM_K_DITHER_ADDR = 5'h17;
    localparam DSM_OUT_SEL_ADDR = 6'h30;
    
    //Other DSM params
    localparam DSM_K_READY_BIT_INDEX = 4'd11;
    //BWCTRL address
    //Bit 0-3 of addr
    localparam BWCTRL_ADDR = 6'h30;
    //CP_CURRENT address
    //Bit 0-2 of addr
    localparam CP_CURRENT_ADDR = 6'h31;
    
    // VCODIV address
    localparam VCO_ADDR = 5'h17;

    localparam DPRIO_IDLE = 3'd0, ONE = 3'd1, TWO = 3'd2, THREE = 3'd3, FOUR = 3'd4,
               FIVE = 3'd5, SIX = 3'd6, SEVEN = 3'd7, EIGHT = 4'd8, NINE = 4'd9, TEN = 4'd10,
               ELEVEN = 4'd11, TWELVE = 4'd12, THIRTEEN = 4'd13, FOURTEEN = 4'd14, DPRIO_DONE = 4'd15;
    localparam IDLE = 2'b00, WAIT_ON_LOCK = 2'b01, LOCKED = 2'b10;
    
    wire            clk;
    wire            reset;
    wire            gnd;

    wire [5: 0]     slave_address;
    wire            slave_read;
    wire            slave_write;
    wire [31: 0]    slave_writedata;

    reg  [31: 0]     slave_readdata_d;
    reg  [31: 0]     slave_readdata_q;
    wire            slave_waitrequest;
    reg             slave_mode;

    assign          clk             = mgmt_clk;
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

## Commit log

2023-08-24 Tweak mode to 224p@60hz
2023-08-28 SMD version of hardware
    [MiSTerLaggy-CuBottom.gbr, MiSTerLaggy-CuTop.gbr, MiSTerLaggy-EdgeCuts.gbr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]
2023-08-31 New circuit design
    [MiSTerLaggy-CuBottom.gbr, MiSTerLaggy-CuTop.gbr, MiSTerLaggy-EdgeCuts.gbr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]
2023-08-31 Switch cpu rom to single 16-bit mif
2023-09-03 MOSFET usage
    [MiSTerLaggy-CuBottom.gbr, MiSTerLaggy-CuTop.gbr, MiSTerLaggy-EdgeCuts.gbr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]
2023-09-03 Add pulldown
    [MiSTerLaggy.kicad_pcb, MiSTerLaggy.kicad_sch]
2023-09-03 Updated step file
    [MiSTerLaggy.step]
2023-09-03 Added USB model
    [GT-USB-7010ASV.step]
2023-09-03 Added USB connector model
    [MiSTerLaggy.kicad_pcb, MiSTerLaggy.step]
2023-09-03 Fix missing connector in step export
    [MiSTerLaggy.kicad_pcb, MiSTerLaggy.step]
2023-09-08 Adjusted layout to make space to isolate the phototransistor
    [MiSTerLaggy-CuBottom.gbr, MiSTerLaggy-CuTop.gbr, MiSTerLaggy-EdgeCuts.gbr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]
2023-09-25 Silkscreen changes
    [MiSTerLaggy-CuBottom.gbr, MiSTerLaggy-CuTop.gbr, MiSTerLaggy-EdgeCuts.gbr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]
2023-09-25 Color UI Fix input mapping
    Enable O3 optimizations
    New color palette and tilemap color behavior
    [main.c]
2023-10-01 Minor tweaks to silkscreen
    [MiSTerLaggy.kicad_pcb, MiSTerLaggy.kicad_sch]
2023-10-01 Removed through hole version since it isn't used or updated.
    [MiSTerLaggy-PCB.step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]
2023-10-10 Added debug output to track timing Added blitter module for fast vram clears
2023-10-11 Use a FIFO to pass pll config info Make core build date available to firmware Tweak colors and layout Detect sensor and show error if not present
    [main.c]
2023-10-12 Display decimals correctly Support more video modes Use CVT mode calculations Disable debug mode
    [main.c]
2023-10-14 Add case models
    [Case - Back Side.stl, Case - Sensor Side.stl, Case.step]
2023-10-14 Support 16:9 and 4:3 mode, allow switching to 16:9 if the resolution supports it. Align widgets to anchors rather than absolute position Disable vscale adjustments
2023-10-30 Add gerbers, BOM and CPL files
    [BOM-MiSTerLaggy.csv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]
2024-11-14 Add edge markers to prevent some displays for auto scaling Allow test to be on left of right Add misterkun logo
    [main.c]
2024-11-14 Update framework
